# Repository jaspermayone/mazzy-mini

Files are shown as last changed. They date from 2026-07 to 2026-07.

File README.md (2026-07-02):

# mazzy mini

A small KiCad PCB for probing and mapping the factory wiring harness of a Mazda vehicle using a Metra 70-7903 pigtail adapter.

## What it does

The board plugs into the factory harness via Metra 70-7903 pigtail ([the one we ordered](https://a.co/d/05tSerNA), 24-pin + 16-pin connectors) and provides:

- **40 through-hole solder/probe pads** (TP1–TP24 for the 24-pin side, TP25–TP40 for the 16-pin side) — one pad per Metra pigtail wire, labeled with known wire color/function or UNKNOWN for unidentified signals. These pads are intended to be soldered to the pigtail wires, not mated as removable connectors.
- **SN65HVD230 CAN transceiver** on 3.3V, wired to CAN_TX/CAN_RX for a Raspberry Pi Pico 2 W (GP4/GP5) to sniff and identify the Mazda MS-CAN bus by jumper-probing the unknown pads.
- **CANH/CANL screw terminal** (J1, Phoenix 1725656) plus CANH/CANL probe pads (TP45/TP46) for jumpering candidate harness wires onto the bus while identifying MS-CAN.
- **Onboard 3.3V LDO** (AMS1117-3.3) fed from a user-selectable BAT12 (constant) or ACC12 (switched) source via JP1 solder jumper.
- **P-channel MOSFET reverse-polarity protection** (PMV100EPAR, Q1) with a 15V gate-source zener clamp, plus a unidirectional SMBJ15A TVS clamp on the 12V input before the regulator.
- **Optional CAN termination** (120Ω R4 across CANH/CANL, **DNP** by default) — leave unpopulated on the already-terminated Mazda factory MS-CAN bus.
- **3.3V power LED** (D1) for quick confirmation that JP1 and the 12V input path are live.
- **USB-C 5V input rail** (J5 receptacle with 5.1kΩ CC pull-downs, ESD TVS, and ferrite bead to 5V_USB) exposed to the Pico header for bench Pico power. It does **not** currently feed the AMS1117/onboard 3V3 rail.
- **Pico 3V3 isolation jumper** (JP3) keeps Pico-facing 3.3V header pins isolated from onboard 3V3 by default to avoid regulator backfeed/fighting.
- **Rail/debug probe pads** — TP41 (3V3), TP42 (5V_USB), TP43 (VIN12), TP44 (GND), TP45 (CANH), TP46 (CANL).

## Known wires (24-pin side)

| Pad | Wire | Function |
|-----|---|---|
| TP1 | Green | BAT12 — constant 12V+ |
| TP2 | Gray | ACC12 — switched 12V+ |
| TP3 | Black | Ground |
| TP4 | White | Front-left speaker + |
| TP5 | Yellow | Front-left speaker − |
| TP6 | Red | Front-right speaker + |
| TP7 | Blue | Front-right speaker − |
| TP8 | White | Rear-left speaker + |
| TP9 | Light green | Rear-left speaker − |
| TP10 | Blue | Rear-right speaker + |
| TP11 | Brown | Rear-right speaker − |
| TP12–TP24 | — | UNKNOWN — map during probing |

TP25–TP40 are the 16-pin pigtail side; all currently UNKNOWN.

## Schematic source

The schematic is defined in Python using [SKiDL](https://github.com/devbisme/skidl) in `circuit.py`. Running it generates the netlist used by KiCad.

```
pip install skidl
python circuit.py
```

The KiCad project files (`circuit.kicad_sch`, `circuit.kicad_pcb`, etc.) are the primary design artifacts and are checked in alongside the source.

## JP1 — power source selection

Solder jumper JP1 selects whether the onboard 3.3V regulator is fed from BAT12 (always on) or ACC12 (ignition-switched). Leave it **open** while mapping unknown harness pins so the board is only powered intentionally.

## R4 — CAN termination (DNP)

R4 (120Ω across CANH/CANL) is marked **do not populate**. The Mazda factory MS-CAN bus is already terminated at both ends. Only fit R4 if you are running a standalone bench test with no other termination present.

## JP3 — Pico 3V3 isolation

Leave **open** by default. J4's 3.3V pin is on `PICO_3V3`, isolated from the onboard AMS1117 `3V3` rail unless JP3 is bridged. This prevents the Pico regulator and onboard regulator from backfeeding each other. Bridge JP3 only when you intentionally want one selected 3.3V source to power both sides.

## USB-C power limitation

`5V_USB` is routed to the Pico-facing header and its probe pad only. It does not diode-OR into the AMS1117 input, so USB-C alone will not power U1/the onboard CAN transceiver unless a future power-OR stage is added.

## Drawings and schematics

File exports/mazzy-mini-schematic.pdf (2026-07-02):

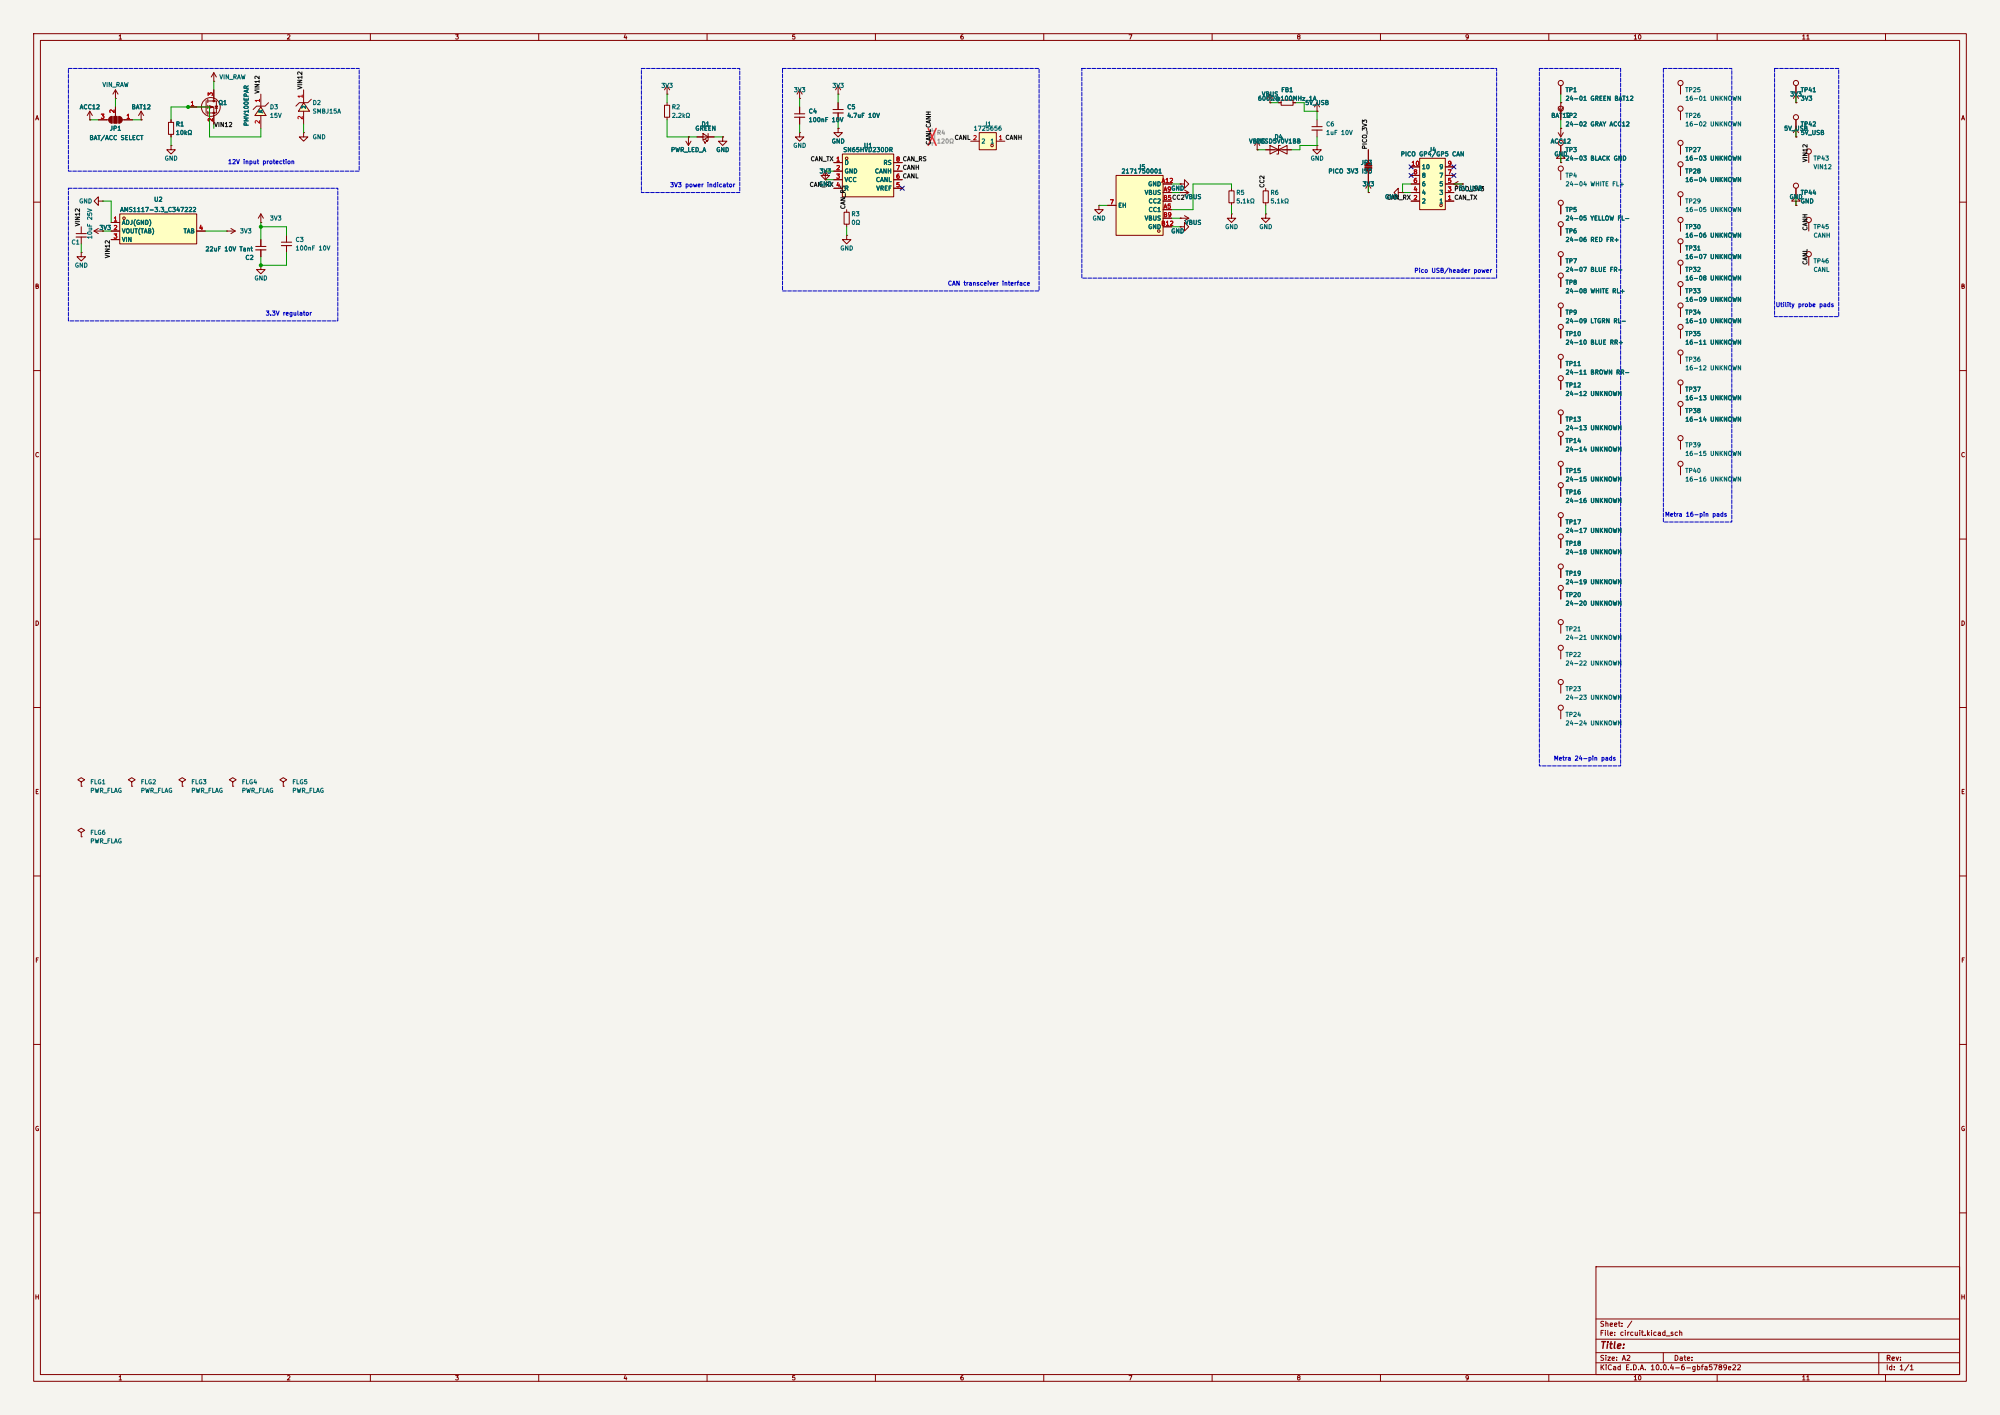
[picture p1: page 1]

Utility probe pads Pico USB/header power C2

Size: A2 | Rev:
KiCad E.D.A. 10.0.4-6-gbfa5789e22 | Id: 1/1

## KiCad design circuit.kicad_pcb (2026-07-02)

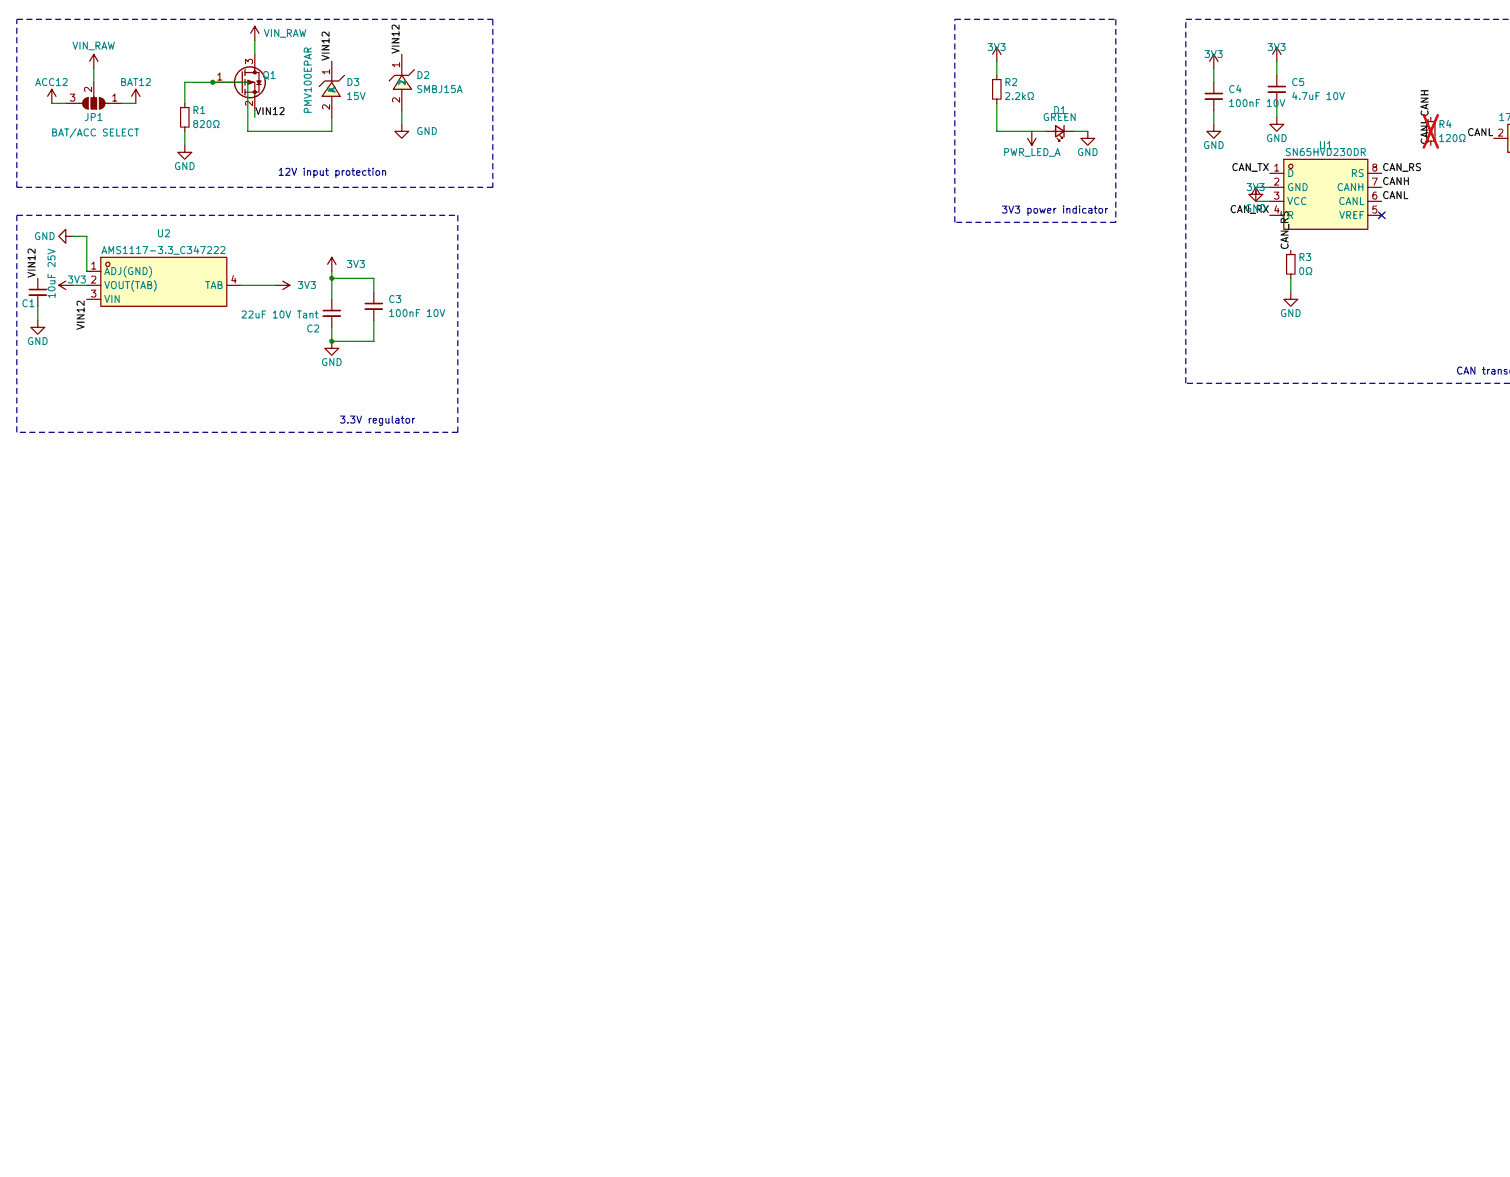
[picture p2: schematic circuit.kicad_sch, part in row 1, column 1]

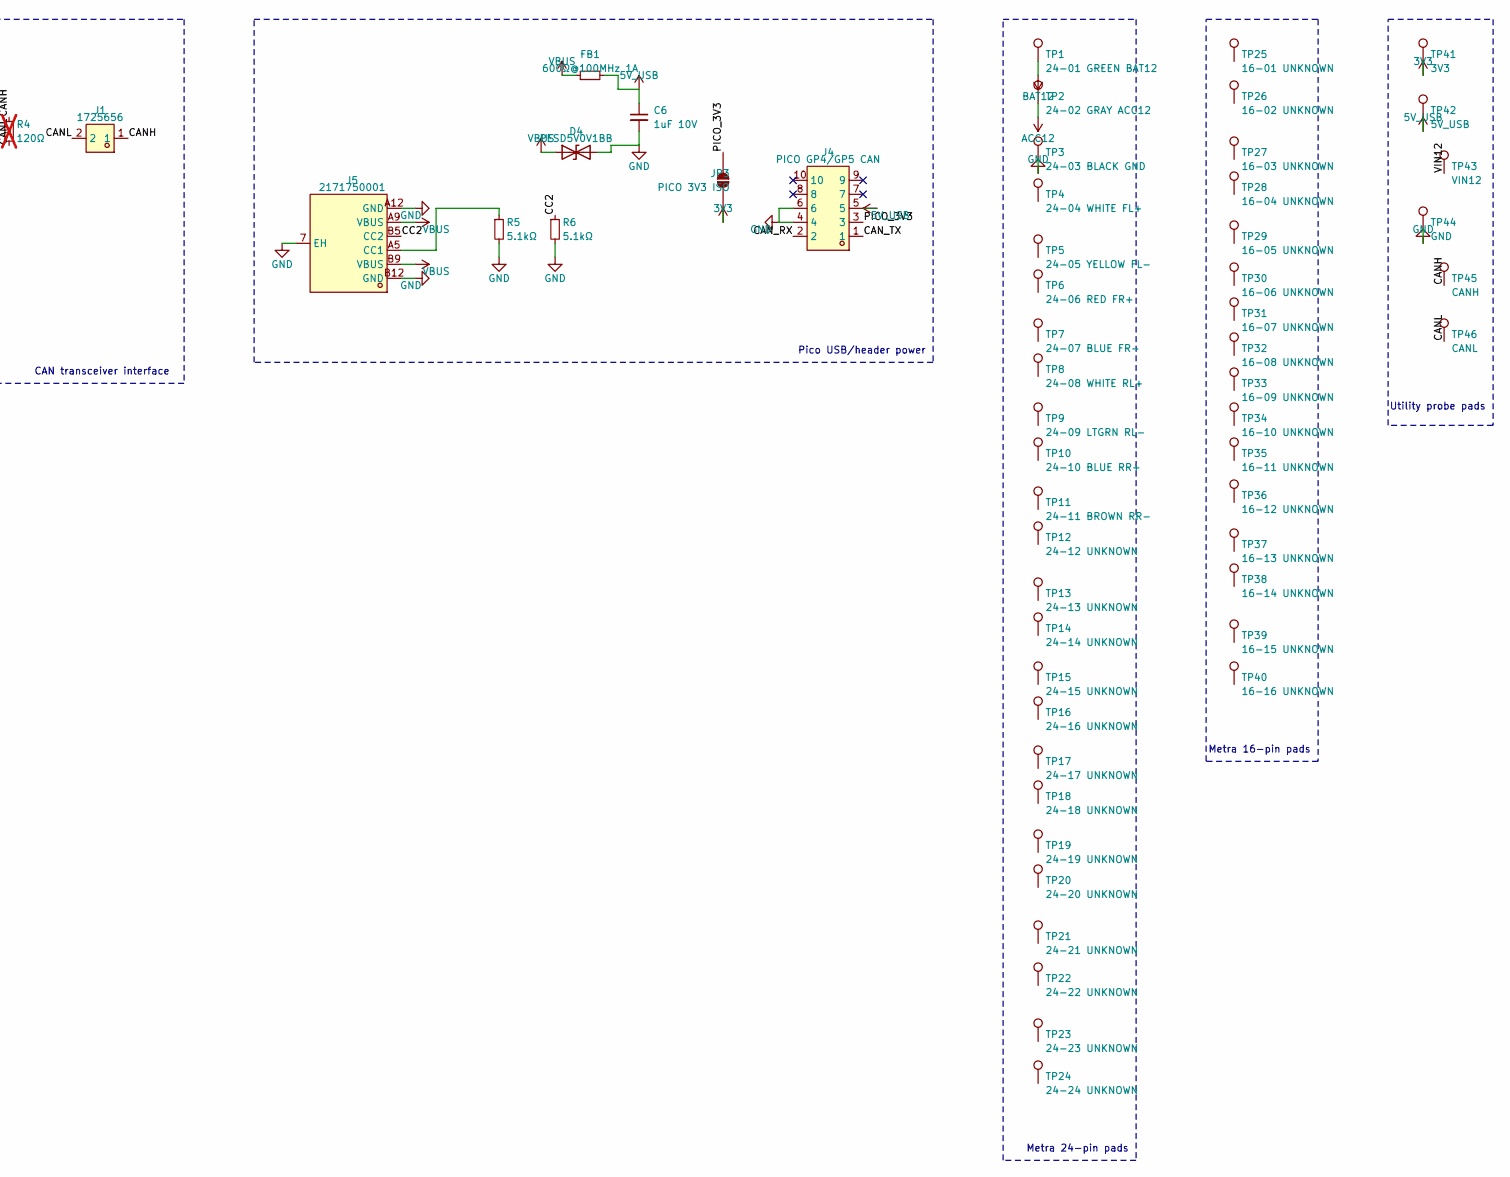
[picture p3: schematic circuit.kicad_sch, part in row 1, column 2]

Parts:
C1: 10uF 25V; C_1206_3216Metric; LCSC Part NONE
C2: 22uF 10V Tant; CP_EIA-3528-21_Kemet-B_HandSolder; LCSC Part NONE
C3, C4: 100nF 10V; C_0603_1608Metric; LCSC Part NONE
C5: 4.7uF 10V; C_0805_2012Metric; LCSC Part NONE
C6: 1uF 10V; C_0603_1608Metric; LCSC Part NONE
D1: GREEN; LED_0603_1608Metric; LCSC Part C20433785
D2: SMBJ15A; SMB_L4.6-W3.6-LS5.3-RD; LCSC Part C83846
D3: 15V; SOD-123_L2.7-W1.6-LS3.7-RD; LCSC Part C129730
D4: PESD5V0V1BB; SOD-523_L1.2-W0.8-LS1.6-RD; LCSC Part C477993
FB1: 600Ω@100MHz 1A; R_0603_1608Metric; LCSC Part C404396
J1: 1725656; CONN-TH_2P-P2.54_1725656; LCSC Part C3029316
J4: PICO GP4/GP5 CAN; HDR-TH_10P-P2.54-V-M-R2-C5-S2.54; LCSC Part C586266
J5: 2171750001; TYPE-C-SMD_TYPE-C-6P_USB4125-GF-A-0190; LCSC Part C3197922
JP1: BAT/ACC SELECT; SolderJumper-3_P2.0mm_Open_TrianglePad1.0x1.5mm; LCSC Part NONE
JP3: PICO 3V3 ISO; SolderJumper-2_P1.3mm_Open_RoundedPad1.0x1.5mm; LCSC Part NONE
Q1: PMV100EPAR; SOT-23-3_L2.9-W1.3-P1.90-LS2.3-BR; LCSC Part C3290636
R1: 820Ω; R_0603_1608Metric; LCSC Part NONE
R2: 2.2kΩ; R_0603_1608Metric; LCSC Part NONE
R3: 0Ω; R_0603_1608Metric; LCSC Part NONE
R4: 120Ω; R_0805_2012Metric; LCSC Part NONE; not fitted
R5, R6: 5.1kΩ; R_0603_1608Metric; LCSC Part NONE
TP1: 24-01 GREEN BAT12; TestPoint_THTPad_D2.5mm_Drill1.2mm; LCSC Part NONE
TP2: 24-02 GRAY ACC12; TestPoint_THTPad_D2.5mm_Drill1.2mm; LCSC Part NONE
TP3: 24-03 BLACK GND; TestPoint_THTPad_D2.5mm_Drill1.2mm; LCSC Part NONE
TP4: 24-04 WHITE FL+; TestPoint_THTPad_D2.5mm_Drill1.2mm; LCSC Part NONE
TP5: 24-05 YELLOW FL-; TestPoint_THTPad_D2.5mm_Drill1.2mm; LCSC Part NONE
TP6: 24-06 RED FR+; TestPoint_THTPad_D2.5mm_Drill1.2mm; LCSC Part NONE
TP7: 24-07 BLUE FR-; TestPoint_THTPad_D2.5mm_Drill1.2mm; LCSC Part NONE
TP8: 24-08 WHITE RL+; TestPoint_THTPad_D2.5mm_Drill1.2mm; LCSC Part NONE
TP9: 24-09 LTGRN RL-; TestPoint_THTPad_D2.5mm_Drill1.2mm; LCSC Part NONE
TP10: 24-10 BLUE RR+; TestPoint_THTPad_D2.5mm_Drill1.2mm; LCSC Part NONE
TP11: 24-11 BROWN RR-; TestPoint_THTPad_D2.5mm_Drill1.2mm; LCSC Part NONE
TP12: 24-12 UNKNOWN; TestPoint_THTPad_D2.5mm_Drill1.2mm; LCSC Part NONE
TP13: 24-13 UNKNOWN; TestPoint_THTPad_D2.5mm_Drill1.2mm; LCSC Part NONE
TP14: 24-14 UNKNOWN; TestPoint_THTPad_D2.5mm_Drill1.2mm; LCSC Part NONE
TP15: 24-15 UNKNOWN; TestPoint_THTPad_D2.5mm_Drill1.2mm; LCSC Part NONE
TP16: 24-16 UNKNOWN; TestPoint_THTPad_D2.5mm_Drill1.2mm; LCSC Part NONE
TP17: 24-17 UNKNOWN; TestPoint_THTPad_D2.5mm_Drill1.2mm; LCSC Part NONE
TP18: 24-18 UNKNOWN; TestPoint_THTPad_D2.5mm_Drill1.2mm; LCSC Part NONE
TP19: 24-19 UNKNOWN; TestPoint_THTPad_D2.5mm_Drill1.2mm; LCSC Part NONE
TP20: 24-20 UNKNOWN; TestPoint_THTPad_D2.5mm_Drill1.2mm; LCSC Part NONE
TP21: 24-21 UNKNOWN; TestPoint_THTPad_D2.5mm_Drill1.2mm; LCSC Part NONE
TP22: 24-22 UNKNOWN; TestPoint_THTPad_D2.5mm_Drill1.2mm; LCSC Part NONE
TP23: 24-23 UNKNOWN; TestPoint_THTPad_D2.5mm_Drill1.2mm; LCSC Part NONE
TP24: 24-24 UNKNOWN; TestPoint_THTPad_D2.5mm_Drill1.2mm; LCSC Part NONE
TP25: 16-01 UNKNOWN; TestPoint_THTPad_D2.5mm_Drill1.2mm; LCSC Part NONE
TP26: 16-02 UNKNOWN; TestPoint_THTPad_D2.5mm_Drill1.2mm; LCSC Part NONE
TP27: 16-03 UNKNOWN; TestPoint_THTPad_D2.5mm_Drill1.2mm; LCSC Part NONE
TP28: 16-04 UNKNOWN; TestPoint_THTPad_D2.5mm_Drill1.2mm; LCSC Part NONE
TP29: 16-05 UNKNOWN; TestPoint_THTPad_D2.5mm_Drill1.2mm; LCSC Part NONE
TP30: 16-06 UNKNOWN; TestPoint_THTPad_D2.5mm_Drill1.2mm; LCSC Part NONE
TP31: 16-07 UNKNOWN; TestPoint_THTPad_D2.5mm_Drill1.2mm; LCSC Part NONE
TP32: 16-08 UNKNOWN; TestPoint_THTPad_D2.5mm_Drill1.2mm; LCSC Part NONE
TP33: 16-09 UNKNOWN; TestPoint_THTPad_D2.5mm_Drill1.2mm; LCSC Part NONE
TP34: 16-10 UNKNOWN; TestPoint_THTPad_D2.5mm_Drill1.2mm; LCSC Part NONE
TP35: 16-11 UNKNOWN; TestPoint_THTPad_D2.5mm_Drill1.2mm; LCSC Part NONE
TP36: 16-12 UNKNOWN; TestPoint_THTPad_D2.5mm_Drill1.2mm; LCSC Part NONE
TP37: 16-13 UNKNOWN; TestPoint_THTPad_D2.5mm_Drill1.2mm; LCSC Part NONE
TP38: 16-14 UNKNOWN; TestPoint_THTPad_D2.5mm_Drill1.2mm; LCSC Part NONE
TP39: 16-15 UNKNOWN; TestPoint_THTPad_D2.5mm_Drill1.2mm; LCSC Part NONE
TP40: 16-16 UNKNOWN; TestPoint_THTPad_D2.5mm_Drill1.2mm; LCSC Part NONE
TP41: 3V3; TestPoint_THTPad_D2.0mm_Drill1.0mm; LCSC Part NONE
TP42: 5V_USB; TestPoint_THTPad_D2.0mm_Drill1.0mm; LCSC Part NONE
TP43: VIN12; TestPoint_THTPad_D2.0mm_Drill1.0mm; LCSC Part NONE
TP44: GND; TestPoint_THTPad_D2.0mm_Drill1.0mm; LCSC Part NONE
TP45: CANH; TestPoint_THTPad_D2.0mm_Drill1.0mm; LCSC Part NONE
TP46: CANL; TestPoint_THTPad_D2.0mm_Drill1.0mm; LCSC Part NONE
U1: SN65HVD230DR; SOIC-8_L4.9-W3.9-P1.27-LS6.0-BL; LCSC Part C12084
U2: AMS1117-3.3_C347222; SOT-223-4_L6.5-W3.5-P2.30-LS7.0-BR; LCSC Part C347222

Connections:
3V3: C2.1, C3.1, C4.1, C5.1, JP3.1 (A), R2.1, TP41.1, U1.3 (VCC), U2.2 (VOUT(TAB)), U2.4 (TAB)
5V_USB: C6.1, FB1.2, J4.5, TP42.1
ACC12: JP1.3 (B), TP2.1
BAT12: JP1.1 (A), TP1.1
CANH: J1.1, R4.1, TP45.1, U1.7 (CANH)
CANL: J1.2, R4.2, TP46.1, U1.6 (CANL)
CAN_RS: R3.1, U1.8 (RS)
CAN_RX: J4.2, U1.4 (R)
CAN_TX: J4.1, U1.1 (D)
CC1: J5.A5 (CC1), R5.1
CC2: J5.B5 (CC2), R6.1
FL_SPK_N: TP5.1
FL_SPK_P: TP4.1
FR_SPK_N: TP7.1
FR_SPK_P: TP6.1
GND: C1.2, C2.2, C3.2, C4.2, C5.2, C6.2, D1.1 (K), D2.2, D4.2 (A2), J4.4, J4.6, J5.7 (EH), J5.A12 (GND), J5.B12 (GND), R1.2, R3.2, R5.2, R6.2, TP3.1, TP44.1, U1.2 (GND), U2.1 (ADJ(GND))
H16_01: TP25.1
H16_02: TP26.1
H16_03: TP27.1
H16_04: TP28.1
H16_05: TP29.1
H16_06: TP30.1
H16_07: TP31.1
H16_08: TP32.1
H16_09: TP33.1
H16_10: TP34.1
H16_11: TP35.1
H16_12: TP36.1
H16_13: TP37.1
H16_14: TP38.1
H16_15: TP39.1
H16_16: TP40.1
H24_12: TP12.1
H24_13: TP13.1
H24_14: TP14.1
H24_15: TP15.1
H24_16: TP16.1
H24_17: TP17.1
H24_18: TP18.1
H24_19: TP19.1
H24_20: TP20.1
H24_21: TP21.1
H24_22: TP22.1
H24_23: TP23.1
H24_24: TP24.1
PICO_3V3: J4.3, JP3.2 (B)
PWR_LED_A: D1.2 (A), R2.2
RL_SPK_N: TP9.1
RL_SPK_P: TP8.1
RP_GATE: D3.2 (A), Q1.1 (G), R1.1
RR_SPK_N: TP11.1
RR_SPK_P: TP10.1
VBUS: D4.1 (A1), FB1.1, J5.A9 (VBUS), J5.B9 (VBUS)
VIN12: C1.1, D2.1, D3.1 (K), Q1.2 (S), TP43.1, U2.3 (VIN)
VIN_RAW: JP1.2 (C), Q1.3 (D)

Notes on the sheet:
CAN transceiver interface
12V input protection
Pico USB/header power
3V3 power indicator
Metra 16-pin pads
3.3V regulator
Metra 24-pin pads
Utility probe pads

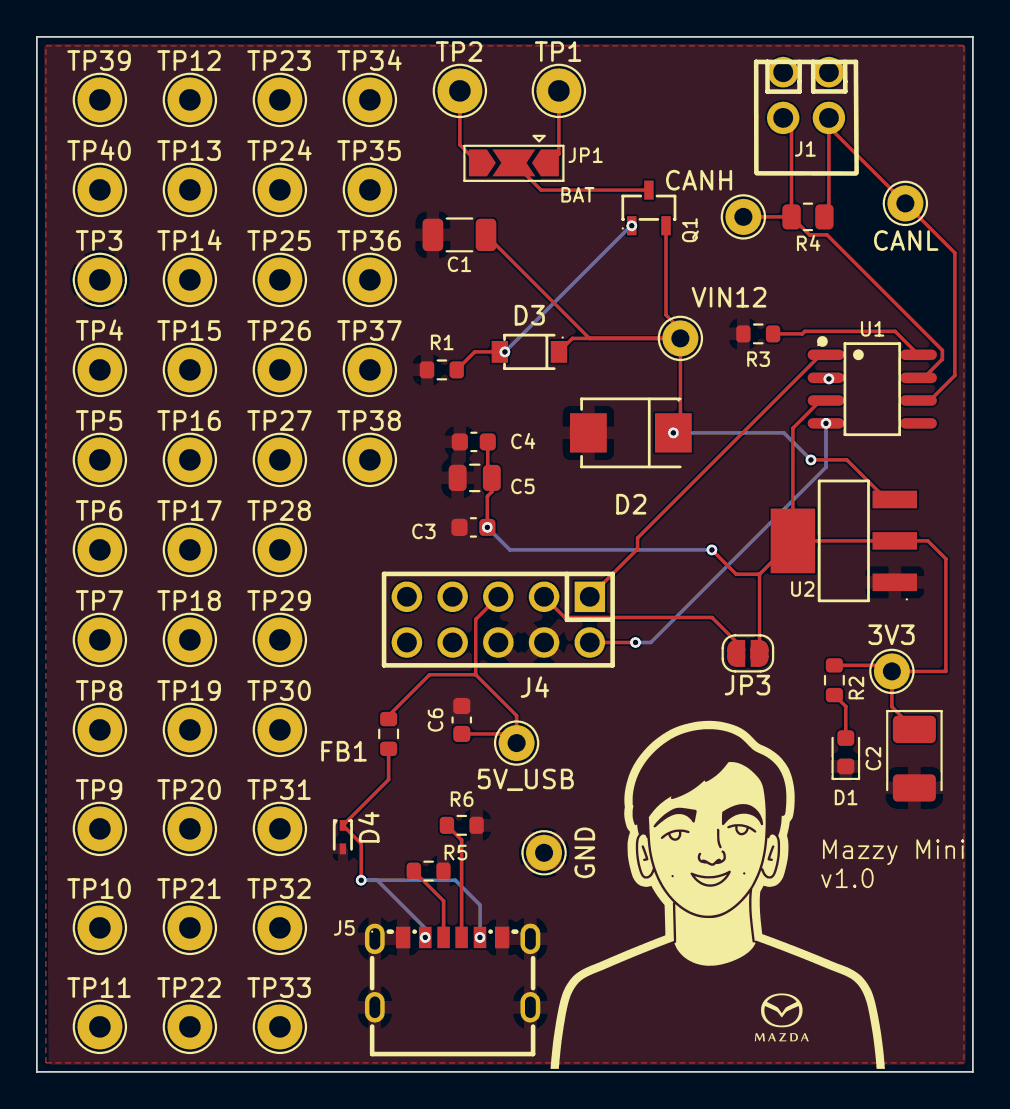
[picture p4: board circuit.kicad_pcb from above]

Board: 2 copper layers, 52.0 x 57.5 mm, 71 parts (0 on the bottom side), 18 nets.

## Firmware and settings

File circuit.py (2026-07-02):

from skidl import *


@requirement("Metra 70-7903 pigtail approach: TP1-TP24 are the 24-pin-side solder/probe pads and TP25-TP40 are the 16-pin-side solder/probe pads.")
@requirement("Every factory-harness pigtail wire must land on one through-hole solder/test pad, TP1 through TP40, with the known function or UNKNOWN in the value label.")
@requirement("U1 SN65HVD230 CAN transceiver must run from 3.3V, expose CAN_TX/CAN_RX for Raspberry Pi Pico 2 W GP4/GP5, and keep CAN termination disabled by default.")
@requirement("U1", "SN65HVD230 pin 2 GND must connect to GND and pin 3 VCC must connect to 3V3; these pins must not be swapped.")
@requirement("Onboard 3.3V must be generated from selectable BAT12 or ACC12 through reverse-polarity P-channel MOSFET protection before the AMS1117-3.3 regulator.")
@requirement("D2", "12V rail transient clamp must be a unidirectional SMBJ15A-class 15V TVS with cathode to VIN12 and anode to GND.")
@requirement("D3", "Q1 gate-source voltage must be clamped by a 15V zener from source/cathode to gate/anode, with R1 gate pull-down sized so continuous dissipation stays within its package rating at 14.4V while the zener self-limits transient VGS.")
@requirement("JP3", "Pico-facing 3.3V header pins must be isolated from the onboard 3V3 rail by a normally-open jumper to prevent regulator backfeed by default.")
@requirement("D4", "USB-C VBUS must have local 5V ESD protection to GND at the connector side of the EMI bead.")
@requirement("FB1", "USB-C VBUS must pass through a ferrite bead before becoming the board 5V_USB rail.")
def build_circuit():
    gnd = Ground("GND")
    bat12 = Power("BAT12", voltage_domain=12.0)
    acc12 = Power("ACC12", voltage_domain=12.0)
    # VIN_RAW/VIN12 are nominally automotive 12V rails, but are intentionally left
    # unannotated because the series MOSFET model uses signed terminal-voltage
    # limits that otherwise produce false voltage-domain ERC errors.
    vin_raw = Net("VIN_RAW")
    vin12 = Net("VIN12")
    v3v3 = Power("3V3", voltage_domain=3.3, current=1.0)
    vbus = Power("VBUS", voltage_domain=5.0)
    v5usb = Power("5V_USB", voltage_domain=5.0)

    can_tx = Net("CAN_TX", voltage_domain=3.3)
    can_rx = Net("CAN_RX", voltage_domain=3.3)
    canh = Net("CANH")
    canl = Net("CANL")
    rp_gate = Net("RP_GATE")
    led_a = Net("PWR_LED_A")
    pico_3v3 = Net("PICO_3V3", voltage_domain=3.3)
    cc1 = Net("CC1")
    cc2 = Net("CC2")
    can_rs = Net("CAN_RS")

    # TP1-TP40 are both the Metra 70-7903 pigtail solder pads and the probe pads.
    # KiCad-side PWR_FLAG markers: these rails are legitimately driven by
    # off-board sources (harness wires, USB-C VBUS) or through passive elements
    # (Q1, FB1), so no schematic symbol has a power-output pin on them. PWR_FLAG
    # satisfies KiCad ERC power_pin_not_driven without changing connectivity.
    pwr_flag_rails = [
        (1, gnd, "Ground enters via the Metra black harness wire (TP3) and USB-C shell/GND pins."),
        (2, bat12, "Constant 12V enters via the Metra green harness wire on TP1."),
        (3, acc12, "Switched 12V enters via the Metra gray harness wire on TP2."),
        (4, vin12, "Protected 12V rail driven through Q1 reverse-polarity MOSFET (passive path)."),
        (5, vbus, "5V enters from the USB-C connector J5 VBUS pins."),
        (6, v5usb, "Filtered 5V rail driven through FB1 ferrite bead (passive path)."),
    ]
    for flag_num, flag_net, flag_reason in pwr_flag_rails:
        pwr_flag = Part("power", "PWR_FLAG", ref="FLG" + str(flag_num))
        pwr_flag.lcsc = "NONE"
        pwr_flag.info = "KiCad ERC power flag; virtual symbol, no physical part. " + flag_reason
        design_intent(
            pwr_flag,
            "KiCad ERC power flag; no physical part. " + flag_reason,
            group="Power flags",
            placement="Virtual symbol; place at the rail entry point on the schematic.",
        )
        flag_net += pwr_flag[1]
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

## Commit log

2026-06-29 inital commit
    [circuit-B_Cu.gbl, circuit-B_Mask.gbs, circuit-B_Silkscreen.gbo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]
2026-06-29 (karl) updates
    [circuit.kicad_pcb, circuit.kicad_sch]
2026-06-29 small updates
    [circuit.kicad_pcb, circuit.kicad_sch]
2026-07-01 more updates
    [circuit.kicad_pcb, circuit.kicad_sch]
2026-07-01 pcb finishing
    [circuit.kicad_pcb, circuit.kicad_sch]
2026-07-01 start organizing schematic
    [circuit.kicad_sch]
2026-07-02 quick updates w/ new review things
    [circuit.kicad_sch]
